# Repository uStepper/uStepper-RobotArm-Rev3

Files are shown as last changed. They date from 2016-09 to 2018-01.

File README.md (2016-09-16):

# uStepper Robot Arm Revision 3

The Robot Arm and uStepper actuators can be purchased on www.ustepper.com/shop

<br /><span xmlns:dct="http://purl.org/dc/terms/" property="dct:title">uStepper</span> by <a xmlns:cc="http://creativecommons.org/ns#" href="www.ustepper.com" property="cc:attributionName" rel="cc:attributionURL">ON Development</a> is licensed under a <a rel="license" href="http://creativecommons.org/licenses/by-nc-sa/4.0/">Creative Commons Attribution-NonCommercial-ShareAlike 4.0 International License</a>.

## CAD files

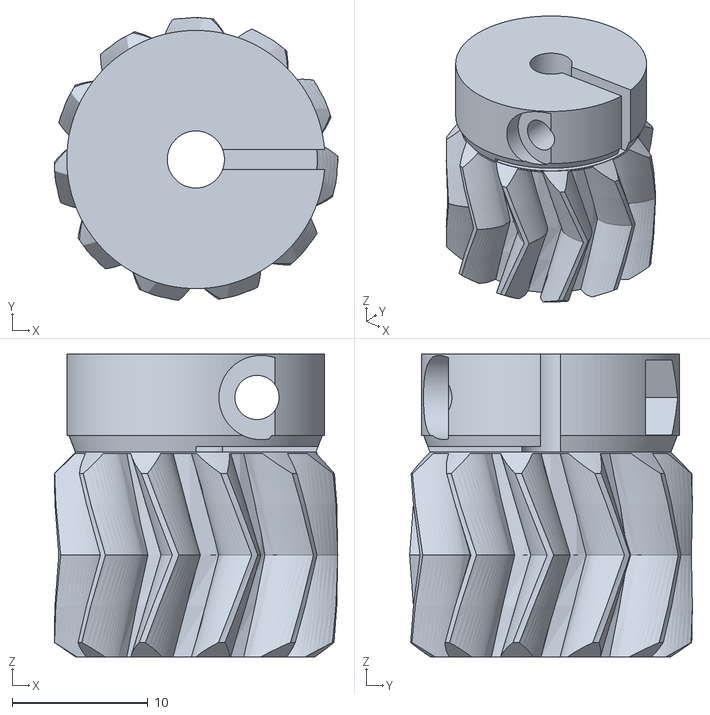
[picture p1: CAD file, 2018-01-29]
STL_files/Gears_main_arm_smallGear_4mm.stl
20.9 x 20.8 x 22.3

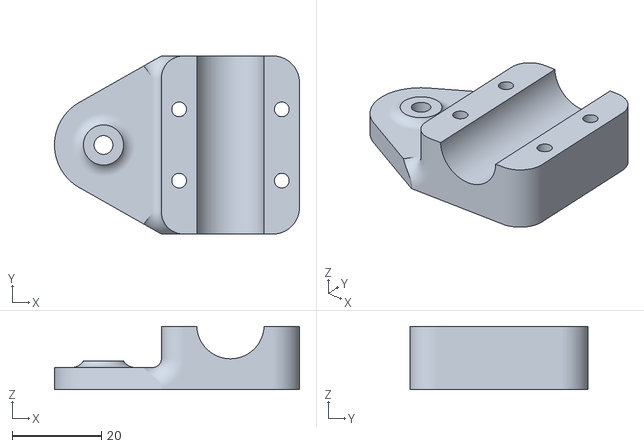
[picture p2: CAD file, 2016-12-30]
STL_files/main_bracket1.stl
55.0 x 40.0 x 14.2

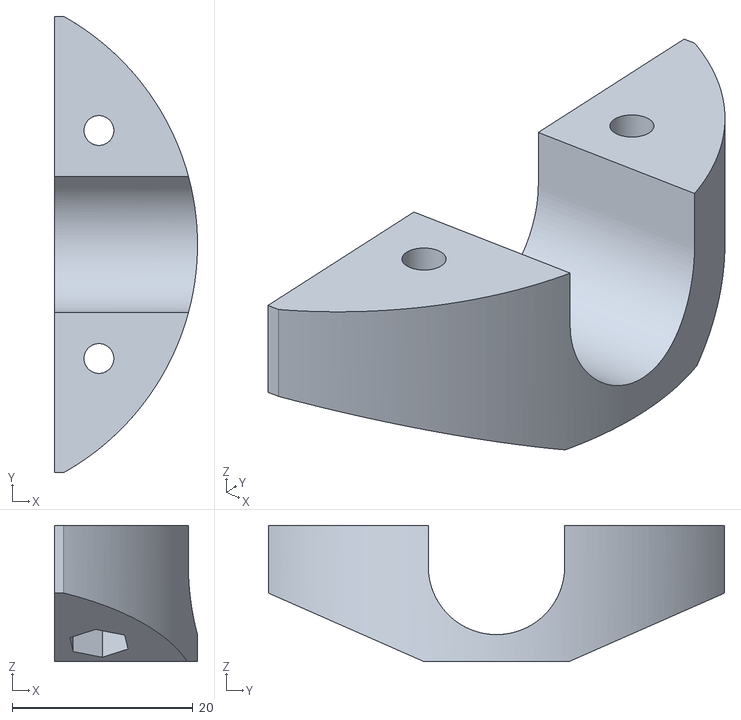
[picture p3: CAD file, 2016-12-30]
STL_files/main_gear_bracket.stl
15.8 x 50.5 x 15.1

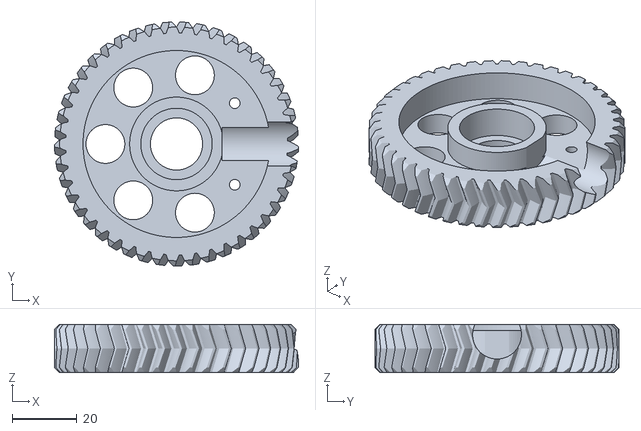
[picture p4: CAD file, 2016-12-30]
STL_files/Gears_main_arm_bigGear.stl
75.5 x 75.5 x 15.0

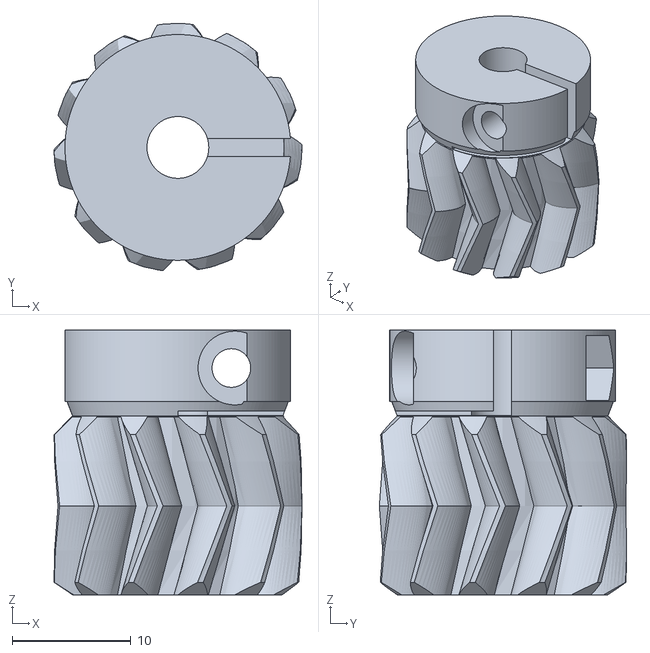
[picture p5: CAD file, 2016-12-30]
STL_files/Gears_main_arm_smallGear.stl
20.9 x 20.8 x 22.3

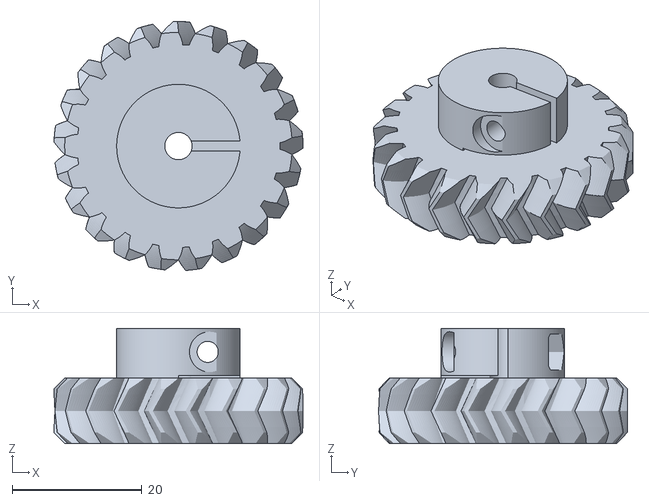
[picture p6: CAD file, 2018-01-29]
STL_files/Gears_bottom_smallGear_4mm.stl
38.3 x 38.3 x 17.7

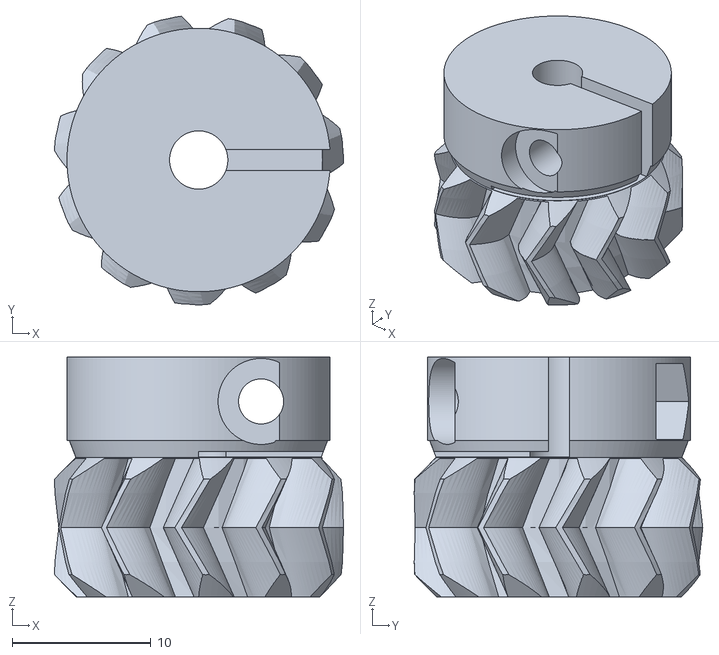
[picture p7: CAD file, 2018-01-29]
STL_files/Gears_second_arm_smallGear_4mm.stl
20.8 x 20.8 x 17.3

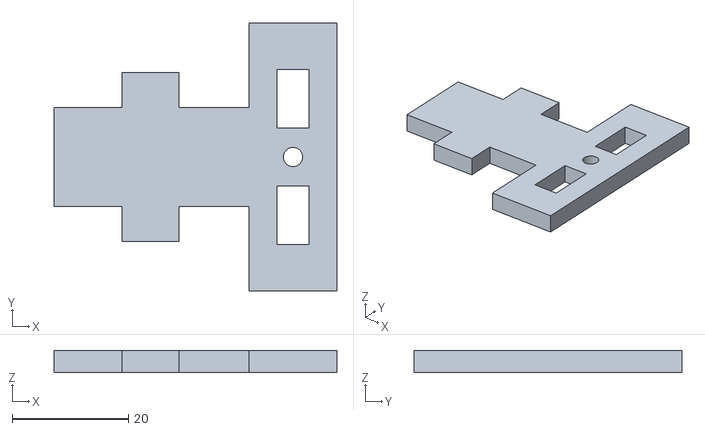
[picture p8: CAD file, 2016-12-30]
STL_files/servo_excluded.stl
48.6 x 46.0 x 3.85

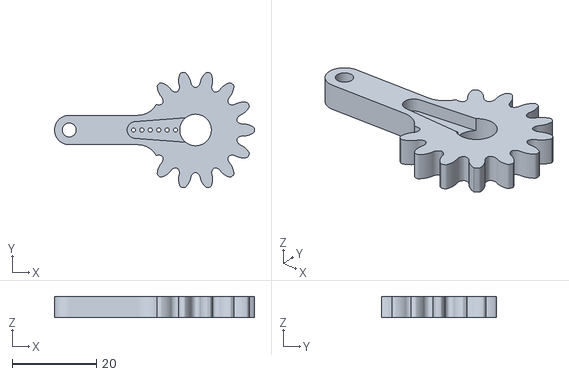
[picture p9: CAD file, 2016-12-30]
STL_files/gripper_servoarm.stl
47.5 x 27.4 x 5.00

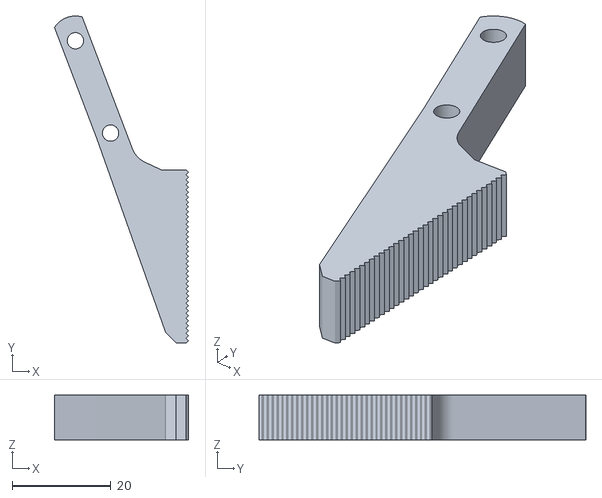
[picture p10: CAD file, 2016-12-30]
STL_files/gripper_1.stl
27.1 x 66.1 x 9.00

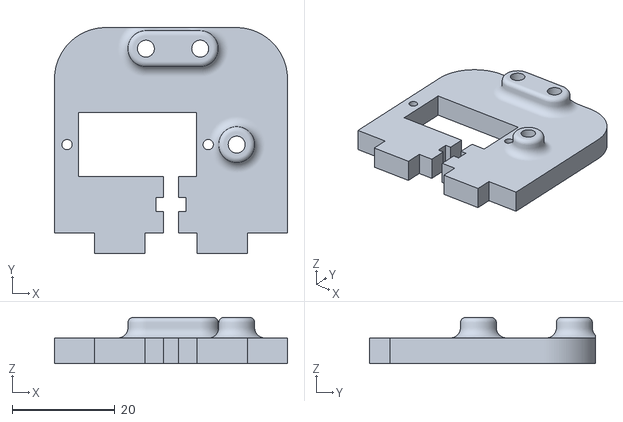
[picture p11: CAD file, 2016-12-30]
STL_files/gripperbase.stl
45.4 x 44.0 x 9.00

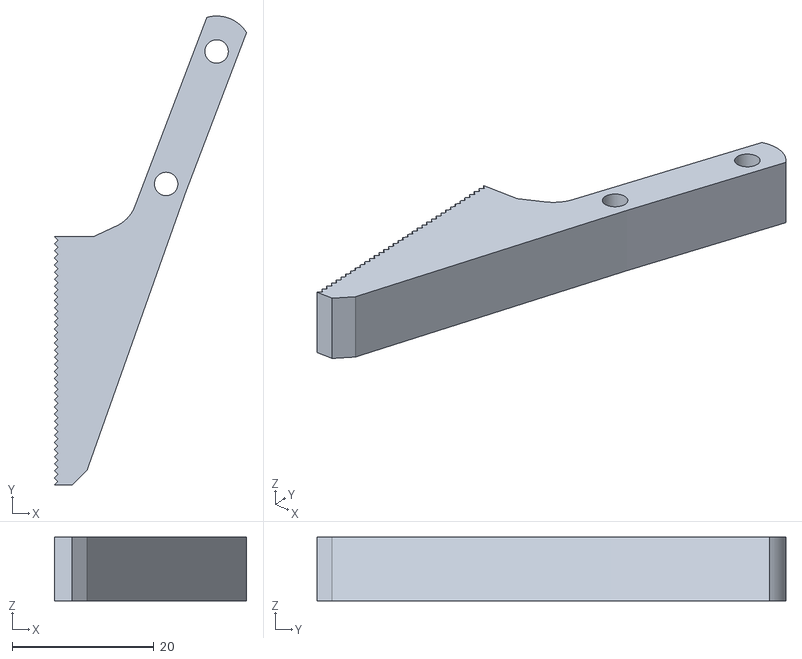
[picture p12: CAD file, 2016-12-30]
STL_files/gripper_2.stl
27.1 x 66.1 x 9.00

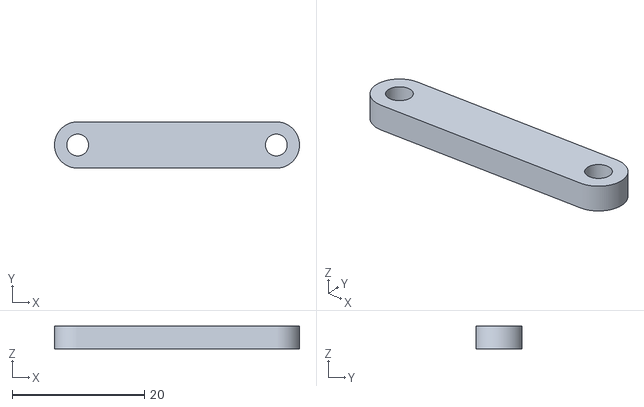
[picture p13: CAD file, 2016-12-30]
STL_files/gripper_link.stl
37.0 x 7.00 x 3.40

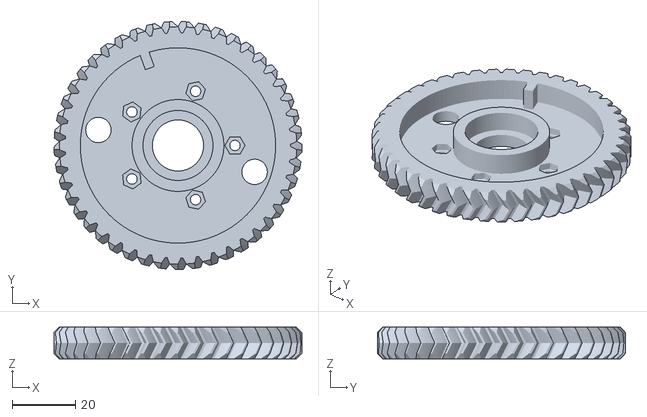
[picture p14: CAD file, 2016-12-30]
STL_files/Gears_bottom_bigGear.stl
78.3 x 78.3 x 10.00

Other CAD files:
STL_files/main_bracket2.stl
STL_files/gripper_freewheel.stl
STL_files/Gears_bottom_smallGear.stl
STL_files/spacer_M4_short.stl
STL_files/Gears_second_arm-Biggear.stl
STL_files/Gears_second_arm_smallGear.stl
STL_files/M3_nut_cover.stl
STL_files/M4_nut_cover.stl
STL_files/M4_nut_cover_long.stl
STL_files/M8_nut_Cover.stl
STL_files/baseplate.stl
STL_files/bottom.stl
STL_files/endtriangle1_rev2.stl
STL_files/endtriangle2_rev2.stl
STL_files/link.stl
STL_files/rod_end_15mm.stl
STL_files/rod_end_15mm_mirror.stl
STL_files/second_gear_arm.stl
STL_files/side1.stl
STL_files/side2.stl
STL_files/spacer_M4_long.stl
STL_files/spacer_M8_long.stl
STL_files/spacer_M8_short.stl
STL_files/triangle.stl

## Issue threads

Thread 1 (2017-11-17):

Step File

quangphuc91, 2017-11-17:
Hi

Can you share me the step file of uStepper Robot , i need to modify hole dimension and some part to fix with my printer because some hole small after printed

My email : quangphuc91@gmail.com

thank you very much

Have a nice day

ChrisPetit, 2018-01-29:
Can the Small Gears also be released with 4mm holes? If not can the Step files for those gears made available so I can change the Axis hole diameter myself?

Thanks

uStepper, 2018-01-29:
Hi,

I dont have the design as a step file.

Best regards,
Mogens

Closed 2018-01-29.

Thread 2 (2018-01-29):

Axis Diameter for small gears

ChrisPetit, 2018-01-29:
Can the Small Gears also be released with 4mm holes? If not can the original files for those gears made available so I can change the Axis hole diameter myself?

Thanks

uStepper, 2018-01-29:
Done

Closed 2018-01-29.

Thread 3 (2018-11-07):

Problem with slave communication

BeebBenjamin, 2018-11-07:
Hi,
I am using the example code here with usteppers on another hobby project of mine.  I have built the blue tooth module and protoshield as per the instructable.  However, there seems to be a problem with the way the software talks to the slaves.  Communication from slave 1 is fine, it occurs almost instantaneously.  However, then I try and run a stepper from the slave 2 slot, communication lags by minutes or even not at all.  Am I missing a trick with the firmware?  I have tested both slaves on slave 1 and slave 2 and both work on slave 1 and both misbehave on slave 2.  I have checked my soldering even redoing it, but the problem is still present.  From your fritzing diagram and the example code you have here I assumed that both Rx lines to the slaves are connected to pin 5 of the master?

Here is the test example I am using:

#include <uStepper.h>
#include <SoftwareSerial.h>
#define SLAVEOUT 2
#define MICROSTEP 16//microstep setting of uStepper
#define RES (200.0*MICROSTEP)/360.0//calculate step pr. degree
#define STEPPRMM 53.55//step pr. mm for the rail used in the demo
#define MMPRSTEP 1/STEPPRMM//mm pr. step
#define MMPRDEG MMPRSTEP*RES//mm pr. degree

SoftwareSerial mySerial(4, 5); // RX, TX

uStepper stepper;

char val;

void setup() {
  Serial.begin(9600);//Setup serial communication on TX/RX
  mySerial.begin(9600);
  stepper.setup(PID,SIXTEEN,10,5,2.0,2.0,0.6);//enable PID
  stepper.setCurrent(50.0);//use software current setting
  stepper.setMaxAcceleration(20000);
  stepper.setMaxVelocity(4000);
  stepper.hardStop(SOFT);

  pinMode(SLAVEOUT, OUTPUT);//Output on slaves
  pinMode(3, INPUT);//Input from slave 1
  pinMode(8, INPUT);//Input from slave 2
}

void master()//Code running on Master
{
   if(Serial.available() > 0)
  {
    val = Serial.read();
  }
  if( val == 'A' )
  {
    stepper.setup(PID,SIXTEEN,100000,50000,1.0,0.02,0.006,0);
    stepper.hardStop(SOFT);
  }
  if( val == 'B')
  {
    stepper.setup(PID,SIXTEEN,100000,50000,1.0,0.02,0.006,0);
    stepper.runContinous(CCW);
  }
  if( val == 'C')
  {
    stepper.setup(PID,SIXTEEN,10,5,2.0,2.0,0.6);
    stepper.moveToAngle(10, SOFT);
    stepper.setup(PID,SIXTEEN,100000,50000,1.0,0.02,0.006,0);
  }
  if( val == 'D')
  {
   stepper.setup(PID,SIXTEEN,10,5,2.0,2.0,0.6);
   stepper.moveToAngle(360, HARD);
  }
  if( val == 'E')
  {
    mySerial.println('A');
  }
  if( val == 'S')
  {
    mySerial.println('B');
  }
}

void slave()//Slave function - the functionality is pretty much the same as in the Master, so look at the comments there for reference.
{
   if(Serial.available() > 0)
  {
    val = Serial.read();
  }
  if( val == 'A')
  {
    stepper.setup(PID,SIXTEEN,100000,50000,1.0,0.02,0.006,0);
    stepper.hardStop(SOFT);
  }
  if( val =='B')
  {
    stepper.setup(PID,SIXTEEN,100000,50000,1.0,0.02,0.006);
    stepper.runContinous(CCW);
  }
}

void loop() {//comment in the appropriate function

//master();
slave();
}

uStepper, 2018-11-07:
Hi,
It sounds like a wiring problem more than a software related problem, since you, as many others, are using the example code we have provided. This code functions for us and many others. Could you send us an email with info on how you have wired them up - preferably with pictures on sales at ustepper.com ?

Closed 2018-11-07.

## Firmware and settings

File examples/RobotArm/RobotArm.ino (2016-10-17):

/*
*      uStepper Robot Arm example sketch!
*
*
* This sketch requires the interconnection of 3 uSteppers. Two of them will be configured as Slaves and one of them as Master.
* A Master and Slave function is provided, comment in the appropriate one in the loop.
* It is recommended to use a wireless UART module to interface with the Master. This will eliminate the risk of damaging the USB port when the Robot Arm moves.
* 
* The pin configuration can be changed as desired (pin 6 and 7 is used for i2c though, so don't use these)
* 
* Pin connections:
* ---------------------------------------
* |   Master    |         Slave          |
* |--------------------------------------|
* | 5           |  0 (RX on both slaves) |
* | 3           |  2 (slave 1)           |
* | 8           |  2 (slave 2)           |
* | A0 -> Servo |                        |
* | GND         |  GND                   |
* ---------------------------------------
*
* The master will receive commands on what to do from its UART. It will then transmit the necessary commands to the Slaves through the software serial port on pin 4.
* The slaves will perform their operation and respond with a digital signal from their pin 2, which is received on pin 3 or 8 on the Master (depending on which slave responds).
* 
* The commands accepted by the master are as follows:
*
*  R  ->   Record position
*  P  ->   Play recorded sequence
*  S  ->   Stop
*  Q  ->   Gripper close
*  X  ->   Gripper open
* 
* To record a sequence, press R. At every desired recording position, press R again. The code will record the position at each instant where R is pressed. To stop recording press S. To play the sequence, press P.
* The sequence can be run again by pressing P, and a new sequence can be recorded by pressing R.
* 
* For now, the code records the position and plays it without feedback during runtime. This will be implemented in a future release.
* If the motors are connected wrong (i.e. the connector is reversed compared to the arm this coe was written for) the Robot Arm will act strange! BE AWARE of this on the forst run!
* 
* Please be aware that the Robot Arm may do moves that can damage the arm itself or its surroundings. By using this code, you acknowledge that the authors can not be held responsible for damage.
* 
*/

#include <uStepper.h>
#include <SoftwareSerial.h>
#define SLAVEOUT 2
SoftwareSerial mySerial(4, 5); // RX, TX

//acceleration and velocity can be changed to fit your needs
#define MAXACCELERATION 1800         //Max acceleration = 1500 Steps/s^2
#define MAXVELOCITY 1200           //Max velocity = 1100 steps/s

uint8_t record = 0, play = 0, stopped = 0;
uint8_t servoAngle = 160;//init servo angle
uint16_t place = 0, endmove = 0;
int16_t pos[100];//Array for storing the positions recorded
uint8_t servoPos[100] = {200};//Array for storing the positions recorded - init to 200
bool finalMove = 0;
  
uStepper stepper(MAXACCELERATION, MAXVELOCITY);//Setup uStepper with the parameters defined
uStepperServo servo; //Setup a servo

void setup() {
  stepper.setup();
  Serial.begin(9600);//Setup serial communication on TX/RX
  mySerial.begin(9600);
  pinMode(SLAVEOUT, OUTPUT);//Output on slaves
  pinMode(3, INPUT);//Input from slave 1
  pinMode(8, INPUT);//Input from slave 2
  servo.attach(A0);//servo signal pin
  servo.write(160);//start at 160deg servo (open gripper)
  //Menu for serial interface
  Serial.println("CMD   Function");
  Serial.println("-------------------------------------------");
  Serial.println("R     Record position");
  Serial.println("P     Play recorded sequence");
  Serial.println("S     Stop");
  Serial.println("Q     Servo close");
  Serial.println("X     Servo open");    
  Serial.println();
}

//afspil: indlæs servopos array med 200 på hver plads, sig, if servopos<200 - apply stuff, else dont! - skal gøres efter motorerne har kørt!

void master()//Code running on Master
{
  char cmd;
  float error = 0;
  if(play ==1 && finalMove == 1)//If we are running the sequence and we are at our final move
  {
    while(digitalRead(3)==LOW || digitalRead(8)==LOW)//Wait for the two slaves to complete their moves
    {
      uStepperServo::refresh(); 
    }
    while(stepper.getMotorState())//Wait for the master to complete its move
    {
      uStepperServo::refresh(); //keep sending signals to servo
    }
    if(servoPos[place] < 200)//if our array have a value in the "normal" range
    {
      servo.write(servoPos[place]);//write the value in the array
      for(int i = 0; i <50; i++)//refresh servo a couple of times to ensure it is actuated
      {
        uStepperServo::refresh();
        delay(5);
      }
    }
    cmd = 'S';//Send a stop command
    finalMove = 0;//We have done the final move
  }
  else if(play ==1 && place <= endmove)//If we are running the sequence but are not at the final move
  {
    while(digitalRead(3)==LOW || digitalRead(8)==LOW)//Wait for the slaves to complete their moves
    {
      uStepperServo::refresh(); 
    }
    while(stepper.getMotorState())//Wait for the Master to complete its move
    {
      uStepperServo::refresh();//keep sending signals to servo
    }  
    if(servoPos[place] < 200)//if our array have a value in the "normal" range
    {
      servo.write(servoPos[place]);//write the value in the array
      for(int i = 0; i <50; i++)//refresh servo a couple of times to ensure it is actuated
      {
        uStepperServo::refresh(); 
        delay(5);
      }
    }  
    cmd = 'F';//Send F to run the next step in the sequence
  }
  redo://A goto 
  if(play == 0)//If we are not running the sequence
  {
    while(!Serial.available())//Wait for something to come on the serial line
    {
      if(stopped == 0)
      {
        uStepperServo::refresh(); //refresh servo if we are not in stop without breaks
      }
    }
    cmd = Serial.read();//save it in the cmd variable
  }
  switch(cmd){//Switch according to received command
    case 'P'://play squence
      if(record == 1)//If we are recording
      {
        Serial.println("Press STOP to stop recording");
        goto redo;//goto redo mark
      }
      else//If not recording
      {
        play = 1;
        break;
        
      }
      
    case 'R'://record steps
    if(record == 0)//If we were not recording before
    {
      for(int i = 0; i<= 100; i++)
      {
        servoPos[i] = 200;
      }
      stepper.encoder.setHome();//Set current position as home
      place = 0;//Reset the array counter
      stopped = 0;
      record = 1;//Record flag
      stepper.softStop(SOFT);//Stop the stepper without breaks
      mySerial.println('R');//Send record command to Slaves
      Serial.println("Press RECORD to record position - Press STOP to stop recording");
    }
    else if(record == 1)//If we have initialized recording
    {
      mySerial.println('R');//Send record command to slaves
      Serial.print("Position ");//Print position number for convenience
      Serial.print(place);
      Serial.println(" recorded");
      pos[place] = (int16_t)stepper.encoder.getAngleMoved();//Save current position
      servoPos[place] = servoAngle;//save servoposition
      place++;//Increment array counter
    }
      break;
      
    case 'F'://If we are stepping forward (in a play sequence scenario)
      stopped = 0;//Stopped flag = 0
      if(place == endmove)//If we are at the end move
      {
        place = 0;//reset array counter
        finalMove = 1;//set final move flag
      }
      mySerial.println('F');//send step forward command to Slaves
      Serial.print("Moving to position ");//Print where we are going for convenience
      Serial.println(place);
      error = ((int16_t)stepper.encoder.getAngleMoved()-pos[place]);//Do some open loop movement based on current position and position recorded.
      if(error < 0)
      {
        stepper.moveSteps((uint16_t)(-error*8.888889), CCW, HARD);
      }
      else if(error > 0)
      {
        stepper.moveSteps((uint16_t)(error*8.888889), CW, HARD);
      }
      else if(error == 0)
      {
        //
      }
      place++;//increment array counter
      break;
      
    case 'S'://1 press on stop => hard stop, second press => soft stop
      mySerial.println('S');
      if(record == 1)//if we are in recording state
      {
        endmove = place;//set the endmove to the current position
        place = 0;//reset array counter
        record = 0;//reset record flag
        stopped = 0;//reset stopped flag
      }
      play = 0;//reset play sequence flag
      if(stopped == 0)//if stop flag is 0
      {
        Serial.println();
        Serial.println("Stopped with breaks - send STOP again to release breaks");
        stepper.softStop(HARD);//stopped with brakes
        stopped = 1;//set stop flag to 1
      }
      else
      {
        Serial.println("Stopped without breaks");
        Serial.println();
        stepper.softStop(SOFT);//if stopflag was 1 and stop command was sent, deactivate brakes
      }      
      break;
      
    case 'X'://close gripper
    if(record == 1)//if we are in recording state
      {
        if(servoAngle <= 140)//if we are less than max value-20
        {
          servoAngle = servoAngle+20;//increase in steps of 20
          servo.write(servoAngle);
        }
        else
        {
          break;
        }
      }
      break;

    case 'Q'://open gripper
    if(record == 1)//if we are in recording state
      {
        if(servoAngle >= 20)//if we are far enough from lower bound from lower bound
        {
          servoAngle = servoAngle-20;//decrease in steps of 20
          servo.write(servoAngle);
        }
        else
        {
          break;
        }
      }
      break;
      
    default:
    
      break;
  }
}

void slave()//Slave function - the functionality is pretty much the same as in the Master, so look at the comments there for reference.
{
  while(stepper.getMotorState())//if stepper is running
  {
    digitalWrite(SLAVEOUT,LOW);//set pin 2 low
  }
  digitalWrite(SLAVEOUT,HIGH);//if stepper is not running set pin 2 high
  
  char cmd;
  float error = 0;
  while(!Serial.available());
  cmd = Serial.read();//receive commands from the Master
  switch(cmd){
    case 'R':
      if(record == 0)
      {
        stepper.encoder.setHome();
        place = 0;
        stepper.softStop(SOFT);
        record = 1;  
      }
      else if(record == 1)
      {
        pos[place] = (int16_t)stepper.encoder.getAngleMoved();//
        place++;
      }
      break;
      
    case 'F':
      stopped = 0;
      if(place == endmove)
      {
        place = 0;
      }
      digitalWrite(SLAVEOUT,LOW);
      error = ((int16_t)stepper.encoder.getAngleMoved()-pos[place]);
      if(error < 0)
      {
        stepper.moveSteps((uint16_t)(-error*8.888889), CCW, HARD);
      }
      else if(error>0)
      {
        stepper.moveSteps((uint16_t)(error*8.888889), CW, HARD);
      }
      else if(error == 0)
      {
        //
      }
      place++;
      break;
      
    case 'S':
      if(record == 1)
      {
        endmove = place;
        place = 0;
        record = 0;
        stopped = 0;
      }
      if(stopped == 0)
      {
        stepper.softStop(HARD);
        stopped = 1;
      }
      else
      {
        stepper.softStop(SOFT);
      }  
      break;
      
    default:
    
      break;
  }
}

void loop() {//comment in the appropriate function
master(); 
//slave();
}

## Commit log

2016-09-16 Initial commit
    Initial commit of rev3 robot arm
    [M3_nut_cover.stl, M4_nut_cover.stl, M4_nut_cover_long.stl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]
2016-10-10 Robot Arm demo sketch added
    This is the Robot Arm demo sketch used for the video: https://www.youtube.com/watch?v=R0Ovw1ZrGzg
    The code is provided as is. A description of the functionality is provided in the sketch. Please be aware that the Robot Arm may do moves that can damage itself or it surroundings. By using this code, you acknowledge that the authors can not be held responsible for damage.
    [RobotArm.ino]
2016-10-11 missing / in a comment
    [RobotArm.ino]
2016-10-14 Update RobotArm.ino
    removed a semicolon that caused an error in the slave routine.
    [RobotArm.ino]
2016-10-17 Updated with servo
    Demo sketch, now with servo support
2016-11-17 Arm instruction updated
    Warnings inserted at steps where motor gears are tightened to prevent over tightening.
2016-12-04 New motor gears added
    The motor gears was redesigned to make them more durable and give better grip on the motor axis.
    [Gears_bottom_smallGear.stl, Gears_main_arm_smallGear.stl, Gears_second_arm_smallGear.stl]
2016-12-30 Moved STL files
    Files moved into new subfolder and gears added in binary STL format
    [Gears_bottom_bigGear.stl, Gears_bottom_smallGear.stl, Gears_main_arm_bigGear.stl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]
2016-12-30 Gripper STL added
    [gripper_1.stl, gripper_2.stl, gripper_freewheel.stl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]
2016-12-30 Removed old files
    [Gears_bottom_smallGear.stl, Gears_main_arm_smallGear.stl, Gears_second_arm_smallGear.stl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]
2017-02-28 Added revised instructions
    Bolt sizes for motor gears changed from M3x8mm to M3x16mm because of new
    gear design.
2018-01-29 Small gears 4mm shaft
    Uploaded the small gears for 4 mm shaft motors.
    [Gears_bottom_smallGear_4mm.stl, Gears_main_arm_smallGear_4mm.stl, Gears_second_arm_smallGear_4mm.stl]
